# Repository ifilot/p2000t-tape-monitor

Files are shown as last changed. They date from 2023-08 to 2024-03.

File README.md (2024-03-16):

# P2000T Tape Monitor





## Features

This project is still under development. Below a list of features can be found.
Checked features are implemented, unchecked features are work in progress.

- [x] Launch tape files from data cartridge in SLOT2
- [x] Write tape data to data cartridge in SLOT2
- [ ] Write data back to tapes from the data cartridge

## Explainer

In the image below, the working of the data cartridge is schematically shown.
In the conventional approach, the user would start the P2000T and load programs
from the cassette. Under the hood, data is copied from the cassette to the
internal memory after which the program can be started.

The data cartridge essentially imitates this process. Upon boot, a driver is 
loaded from the data cartridge into memory and launched. This driver
scans the external ROM chip for programs and shows a list of those programs. The
user can then select a program and executes it. Upon selection, the program is
first copied from the external chip to the internal RAM chip in the data cartridge.
Next, the driver is unloaded from memory, and the new data is copied from the 
RAM chip to the same position as where normally cassette data is copied. 
Finally, the `RUN` command is executed which starts the program.

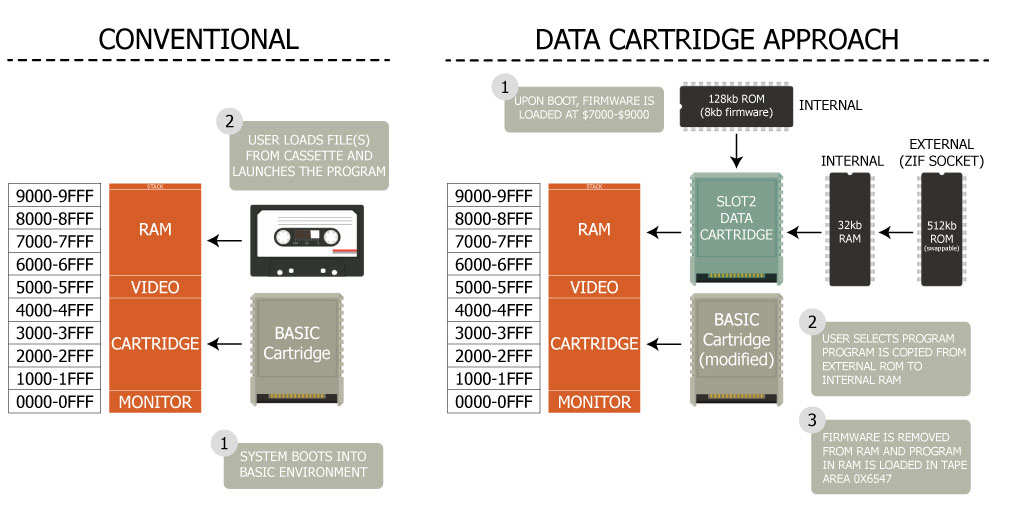
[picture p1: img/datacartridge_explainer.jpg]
Explain how the data cartridge works


## Contents
This repository is organized as follows

* `basicmod`: Modified BASIC ROM. This ROM is needed for the cartridge in SLOT1.
* `cassette-utility`: Source code of the SLOT1 program to copy programs and data
  from the data cassette to the data cartridge.
* `docs`: Technical documentation; mainly needed for development.
* `flasher`: SLOT1 program to transfer the launcher from external ROM chip
  on the data cartridge to the internal ROM.
* `gui`: GUI to add and delete programs from the data cartridge and to format a
  chip.
* `launcher`: Source code of the launcher application.
* `pcb`: PCBs for the SLOT2 data cartridge. Also includes .stl files for the cartridge enclosure.

## Files

The latest version of the files below can be obtained from the action artifacts
of the [last build](https://github.com/ifilot/p2000t-tape-monitor/actions/workflows/build.yml).

* [`BASICBOOTSTRAP.BIN`](https://github.com/ifilot/p2000t-tape-monitor/releases/latest/download/BASICBOOTSTRAP.BIN): 
  Modified BASIC cartridge. This is a SLOT1 cartridge.
* [`CASSETTE_UTILITY.BIN`](https://github.com/ifilot/p2000t-tape-monitor/releases/latest/download/CASSETTE_UTILITY.BIN): 
  Utility for copying files directly from the cassette to the (external) ROM chip. This is a SLOT1 cartridge.
* [`FLASHER.BIN`](https://github.com/ifilot/p2000t-tape-monitor/releases/latest/download/FLASHER.BIN):
  Flasher for the data cartridge driver. This is a SLOT1 cartridge that copies 
  the driver from the external to the internal ROM on the SLOT2 cartridge.
* [`LAUNCHER.BIN`](https://github.com/ifilot/p2000t-tape-monitor/releases/latest/download/LAUNCHER.BIN): 
  Driver for the data cartridge. This driver is stored on the internal ROM of 
  the SLOT2 cartridge.
* [`p2000t-fat-flasher-installer-win64.exe`](https://github.com/ifilot/p2000t-tape-monitor/releases/latest/download/p2000t-fat-flasher-installer-win64.exe): 
  Windows installer for the Flasher GUI. This GUI is used to put cassette files 
  on a ROM chip which can be loaded on the P2000T.

## File system

Data is stored on the ROM using a custom file system. Specifications of the file
system are documented [in a separate file](docs/fat.md).

## FAQ

* Where can I find programs?

  *A rather huge archive of P2000T cassette programs 
  (which is also being actively maintained), can be found in the
  [P2000T Preservation Project](https://github.com/p2000t/software) repository.*
* Where can I find the documentation?

  *All documentation can be found on the [philips-p2000t.nl](https://philips-p2000t.nl) website.*

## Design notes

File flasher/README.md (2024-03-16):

# Flasher

## Purpose

This SLOT1 program allows the user to copy the firmware from bank 1 on an
*external* ROM chip to the *internal* ROM chip.

## Usage

Put the firmware (`launcher-os`) on the external ROM chip and start the P2000T
with this program in SLOT1. Press any key to start the copying procedure. When
done, the copying process is validated on the basis of a checksum. You need
to verify that this checksum matches the expected checksum. The expected 
checksum is provided upon compilation of `launcher-os`.

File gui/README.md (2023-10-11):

# P2000T FAT GUI

## Purpose

User-friendly way of interfacing with P2000T-FAT ROMS using the
PICO-flasher utility.

## Compilation under Linux

Ensure that all dependencies are installed

```bash
sudo apt update && sudo apt install -y qtbase5-dev qt5-qmake libqt5serialport5-dev cmake
```

Create a new build folder and compile the GUI

```
mkdir build && cd build && qmake ../gui && make -j
```

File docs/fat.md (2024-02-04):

# File Allocation Table on ROM chips

This page explains how data is stored on the ROM chips. The Tape monitor uses
the SST39SF0x0 type of ROM chips which contain 128kb, 256kb or 512kb of data
for the 040, 020 and 010 models, respectively.

## Summary

* Each ROM has 2, 4, or 8 banks for a total of 128kb, 256kb, or 512kb of data.
* A bank corresponds to 64kb hosting 60 blocks of 1kb of data each.
* A file is a (not necessarily continuous) set of blocks, corresponding to
  an entry on a tape.
* Each bank has a metadata section of 4kb that holds the metadata of the block
  and of the files.

A schematic overview is given in the figure below.

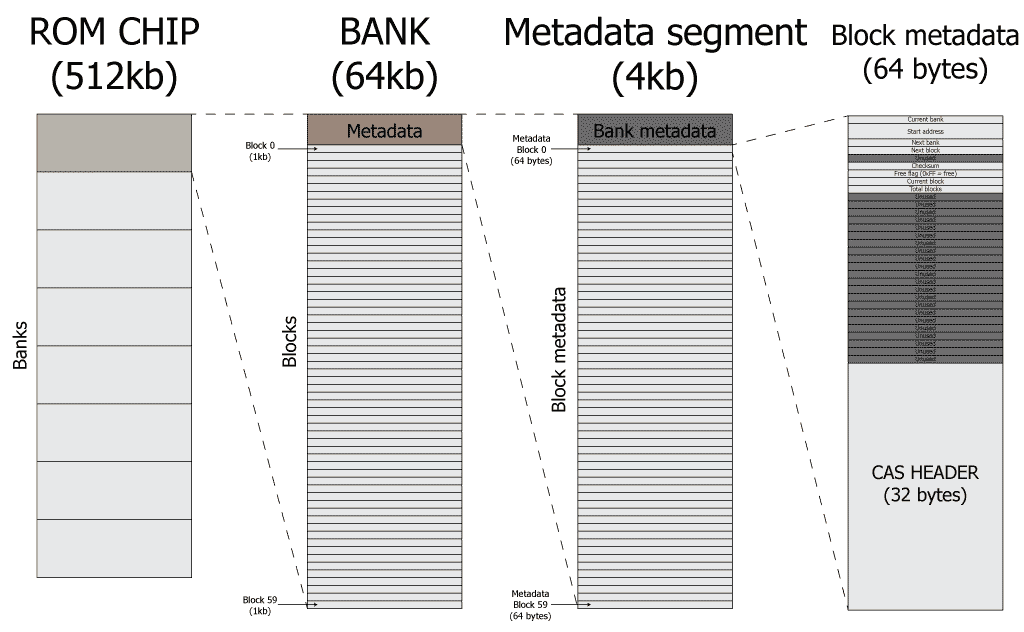
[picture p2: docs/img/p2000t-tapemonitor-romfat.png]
Overview storage model


## Storage model

The first 4kb of each bank are used to store the metadata of that bank. Herein,
the first 256 bytes of the metadata section contain the start blocks for the
files. The next 60 entries correspond to 64 bytes of metadata information for
each block. An schematic overview is provided in the table below.

| Address | Description |
|---|---|
| $0000-$00FF | Bank metadata |
| $0100-$013F | Metadata block 0  |
| $0140-$017F | Metadata block 1  |
| $0180-$01BF | Metadata block 2  |
| $01C0-$01FF | Metadata block 3  |
| $0200-$023F | Metadata block 4  |
| .....-..... | Metadata block i  |
| $0FC0-$0FFF | Metadata block 59 |

Note that because a bank can only contain at most 60 blocks of data, the bank
metadata section will at most use 60 of the in total 256 entries.

### Block metadata

The block metadata segments, each 64kb in size, are divided into a lower and
upper segment. The upper segment is a copy of the cassette metadata as stored
at $6030 in memory when reading from a tape. The upper segment holds a
per block checksum and a reference to the next bank and block if the file
uses more than one block. If not, the default value corresponds to `0xFF`.

| Address | Description | Notes |
|---|---|---|
| $0000 | Current bank  (F)  | |
| $0001-$0002 | Start address (F)  | |
| $0003 | Next bank | $FF when last block |
| $0004 | Next block | $FF when last block |
| $0005 | *Unused* | |
| $0006-$0007 | Checksum | CRC-16, see below |
| $0008 | Free? | $FF if free, else $00 |
| $0009 | Current block | |
| $000A | Total blocks | |
| $000B-$001F | *Unused* | |
| $0020-$003F | CAS header | |

### Storage location of cassette metadata

The CAS header basically corresponds to memory locations $6030-$604F of the
P2000T after reading a block from the cassette. These addresses are hardcoded 
in the P2000T ROM (e.g. 0x0000 - 0x1000) and cannot be changed.

**Note that all values are stored in big endian order**

| Address | RAM Address | Description |
|---|---|---|
| $0020-$0021 | $6030-$6031 | Transfer address |
| $0022-$0023 | $6032-$6033 | File length |
| $0024-$0025 | $6034-$6035 | Record length |
| $0026-$002D | $6036-$603D | Descriptor (1/2) |
| $002E-$0030 | $603E-$6040 | Extension |
| $0031-$0032 | $6041-$6042 | Type |
| $0033-$0034 | $6043-$6044 | Start boot |
| $0035-$0036 | $6045-$6046 | Load |
| $0037-$003E | $6047-$604E | Descriptor (2/2) |
| $003F | $604F | Blocks remaining |

### Checksum

For each 1kb block of data, a 16-bit checksum is generated using the 
CRC-16/XMODEM checksum algorithm. Efficient Z80 source code for the algorithm 
is taken from [here](https://mdfs.net/Info/Comp/Comms/CRC16.htm).
A handy site for generating checksums can be found [here](https://crccalc.com/).

## Formatting

When a ROM is formatted, first all banks are wiped (i.e. set to `0xFF`). Next,
the metadata for each bank is set. This corresponds to 3 bytes per block metadata
section. All other bytes remain at (`0xFF`).

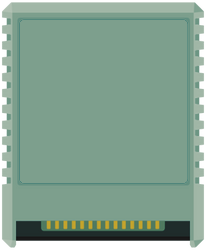
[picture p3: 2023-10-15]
img/cartridge_teal.png

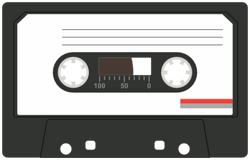
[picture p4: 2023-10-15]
img/cassette.png

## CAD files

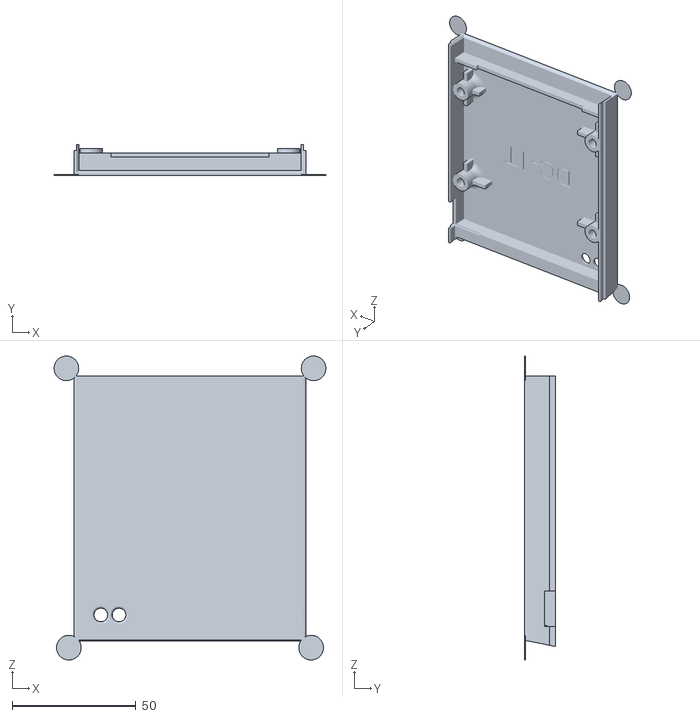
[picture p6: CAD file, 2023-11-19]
pcb/case/p2000t-datacartridge-top.stl
110.0 x 12.5 x 123.0

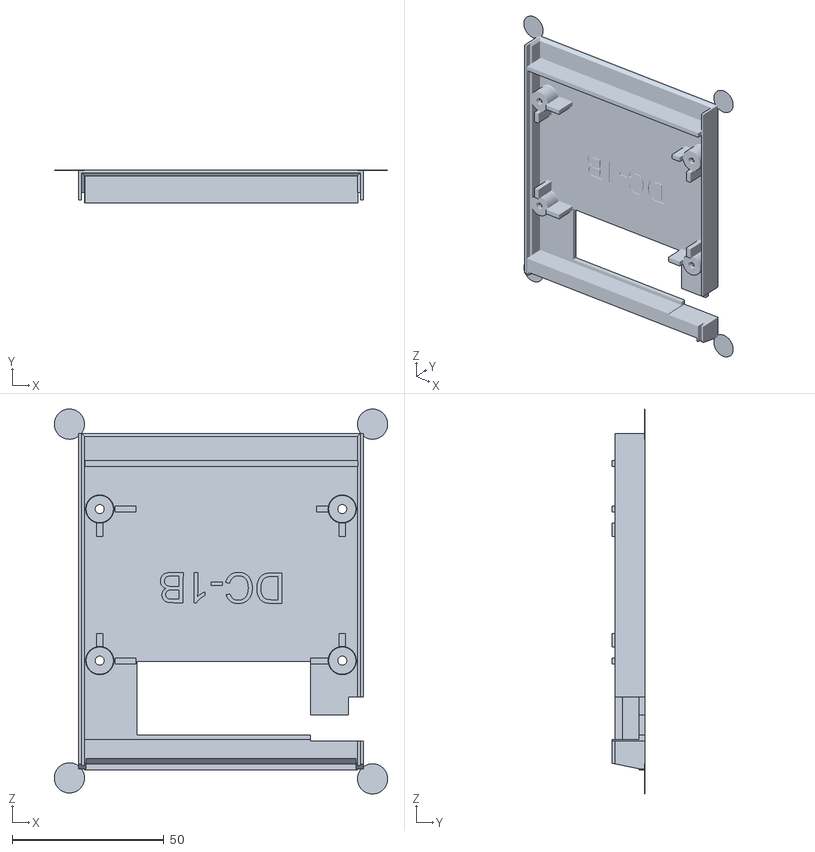
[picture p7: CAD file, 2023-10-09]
pcb/case/p2000t-datacartridge-bottom.stl
110.0 x 11.0 x 127.0

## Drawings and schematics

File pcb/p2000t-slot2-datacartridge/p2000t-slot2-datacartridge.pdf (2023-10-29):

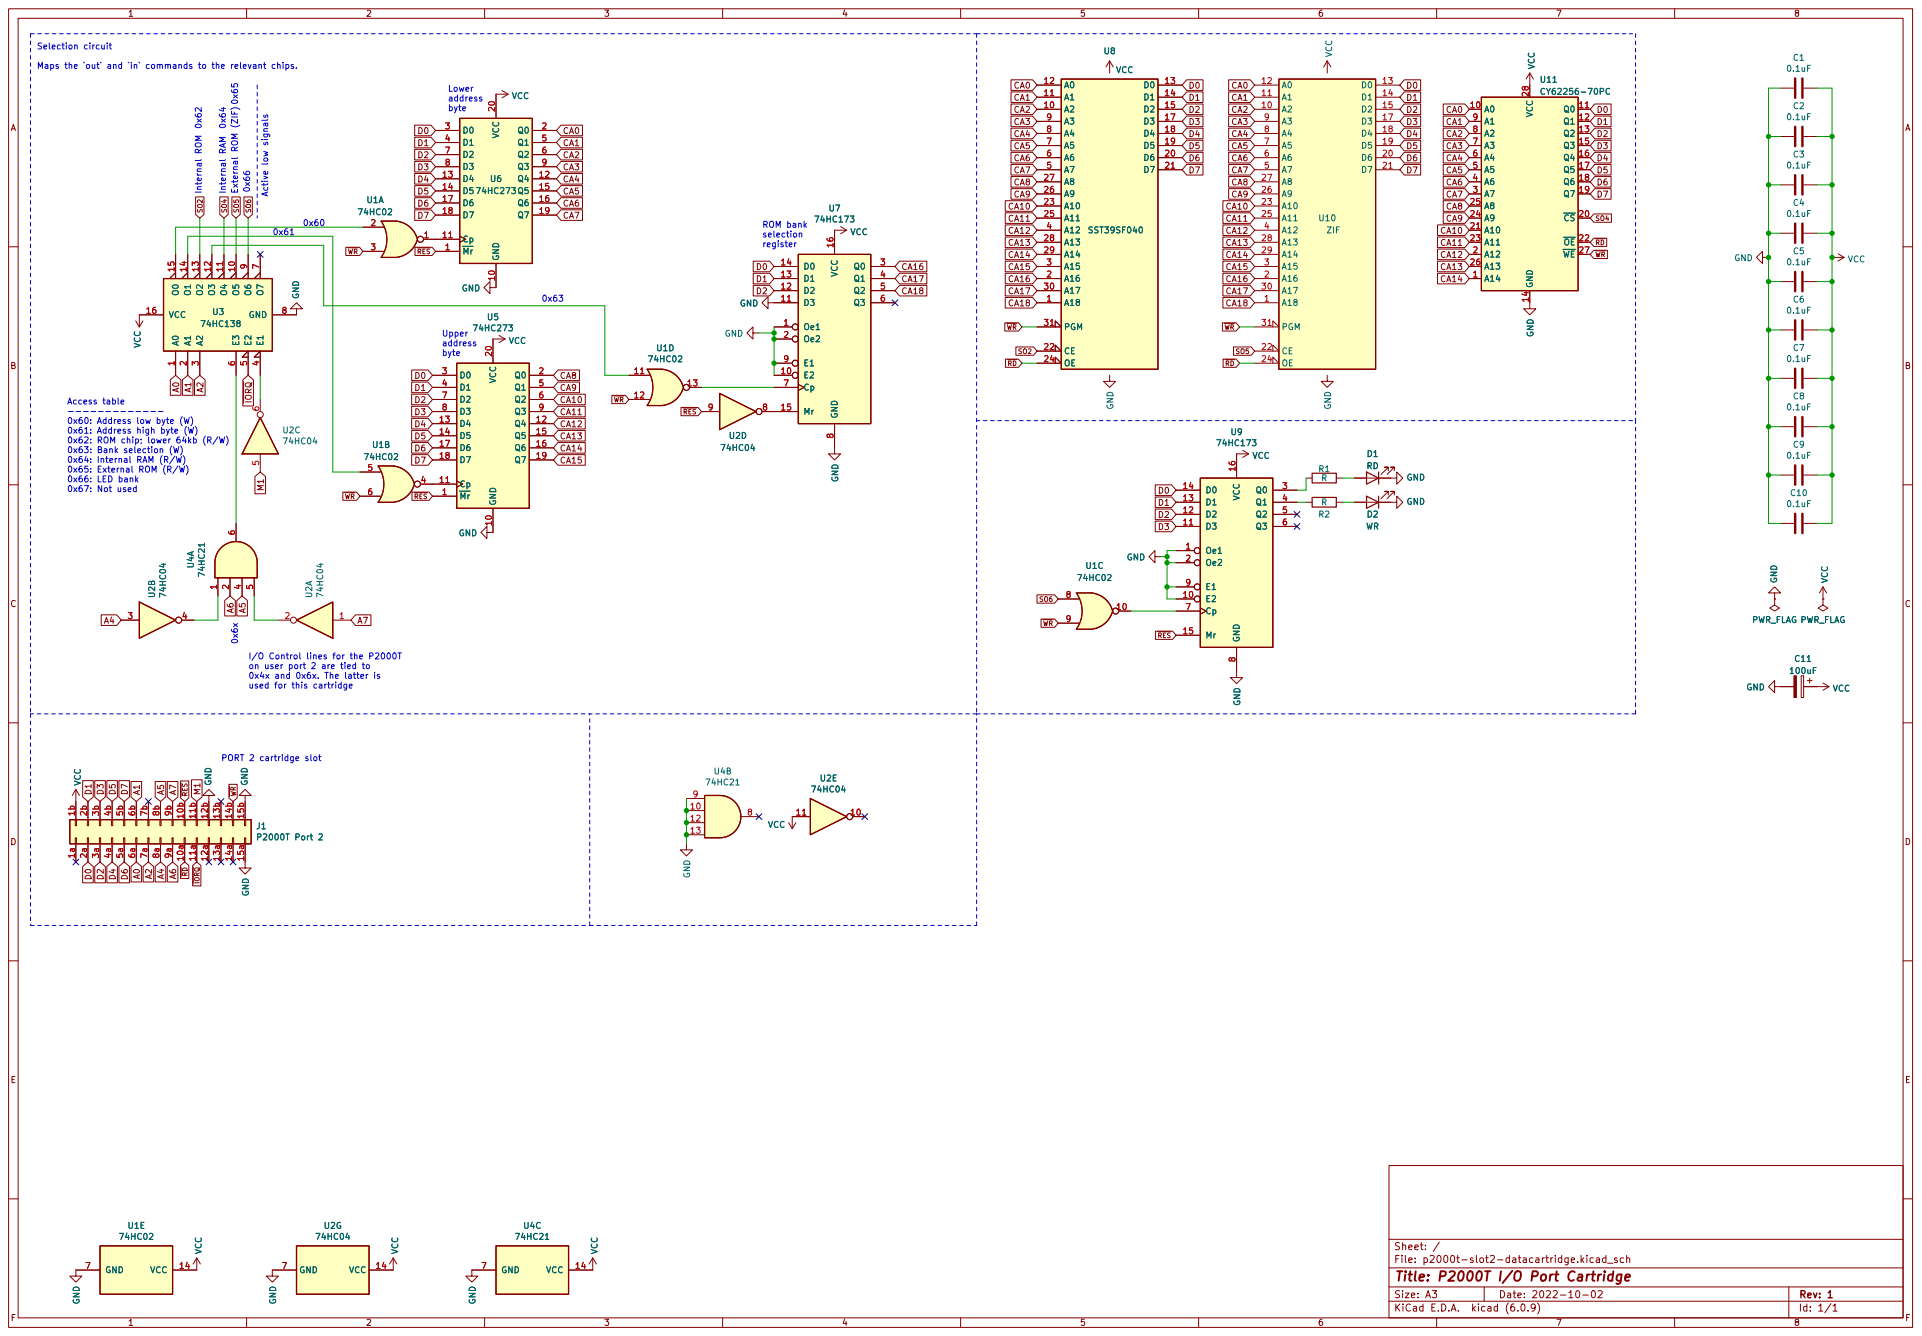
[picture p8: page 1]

PORT 2 cartridge slot 0x64 Selection circuit Maps the `out` and `in` commands to the relevant chips. 0x65

0x4x and 0x6x. The latter is used for this cartridge Access table
------------- 0x60: Address low byte (W)

I/O Control lines for the P2000T
on user port 2 are tied to

File: p2000t-slot2-datacartridge.kicad_sch Sheet: /
Id: 1/1 Title: P2000T I/O Port Cartridge

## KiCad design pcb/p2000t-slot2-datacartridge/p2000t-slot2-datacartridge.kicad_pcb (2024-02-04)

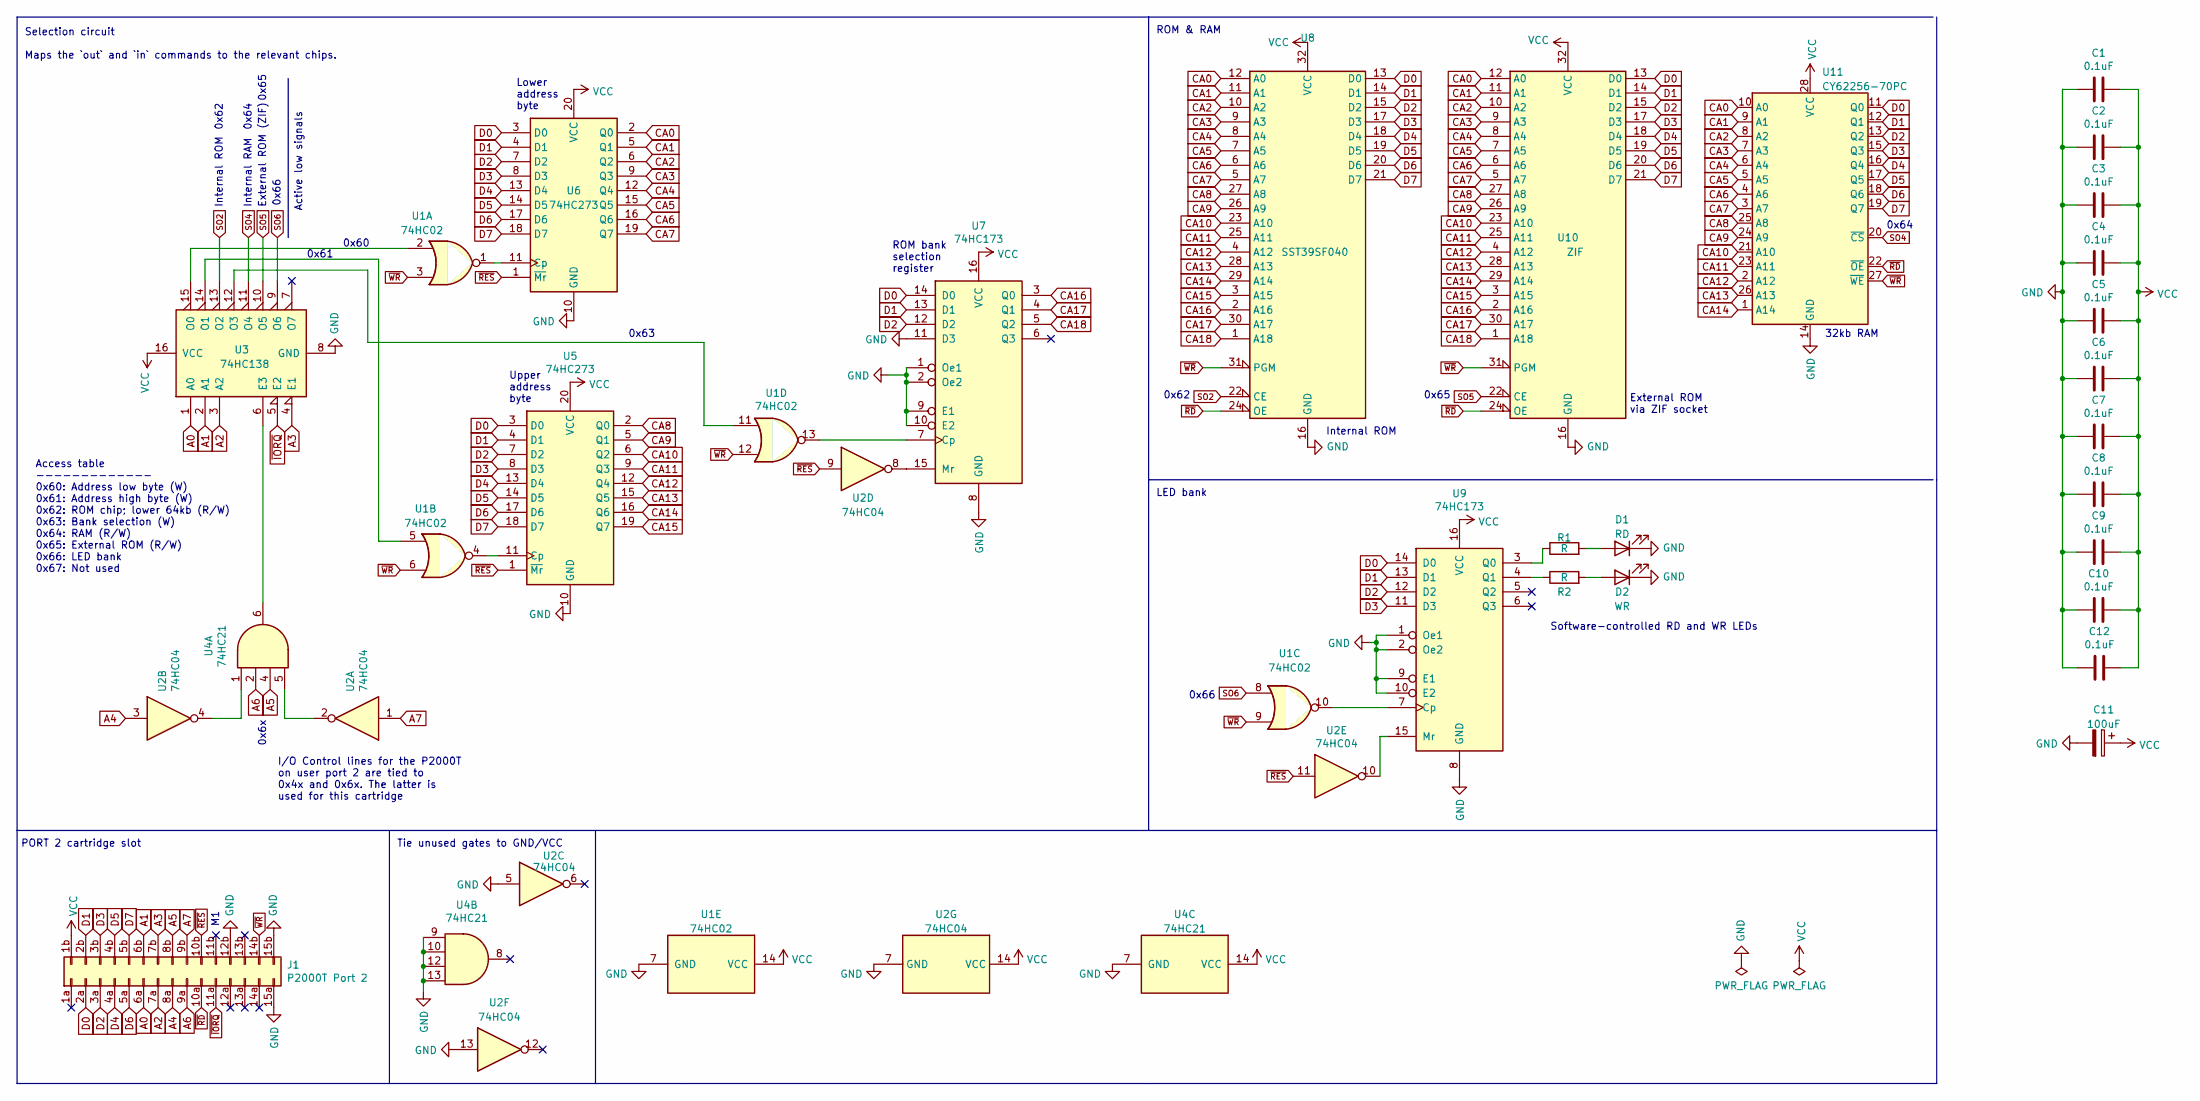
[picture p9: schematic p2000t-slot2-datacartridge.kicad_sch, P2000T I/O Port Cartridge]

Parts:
C1, C2, C3, C4, C5, C6, C7, C8, C9, C10, C12: 0.1uF; C_Disc_D5.0mm_W2.5mm_P5.00mm
C11: 100uF; CP_Radial_D6.3mm_P2.50mm
D1: RD; LED_D5.0mm
D2: WR; LED_D5.0mm
J1: P2000T Port 2; p2000t_cartridge_edge
R1, R2: R; R_Axial_DIN0207_L6.3mm_D2.5mm_P7.62mm_Horizontal
U1: 74HC02; DIP-14_W7.62mm_Socket
U2: 74HC04; DIP-14_W7.62mm_Socket
U3: 74HC138; DIP-16_W7.62mm_Socket
U4: 74HC21; DIP-14_W7.62mm_Socket
U5, U6: 74HC273; DIP-20_W7.62mm_Socket
U7, U9: 74HC173; DIP-16_W7.62mm_Socket
U8: SST39SF040; PLCC-32_THT-Socket
U10: ZIF; DIP_Socket-32_W11.9_W12.7_W15.24_W17.78_W18.5_3M_232-1285-0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
U11: CY62256-70PC; DIP-28_W15.24mm_Socket

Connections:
A0: J1.6a, U3.1 (A0)
A1: J1.6b, U3.2 (A1)
A2: J1.7a, U3.3 (A2)
A3: J1.7b, U3.4 (E1)
A4: J1.8a, U2.3
A5: J1.8b, U4.4
A6: J1.9a, U4.2
A7: J1.9b, U2.1
CA0: U6.2 (Q0), U8.12 (A0), U10.12 (A0), U11.10 (A0)
CA1: U6.5 (Q1), U8.11 (A1), U10.11 (A1), U11.9 (A1)
CA2: U6.6 (Q2), U8.10 (A2), U10.10 (A2), U11.8 (A2)
CA3: U6.9 (Q3), U8.9 (A3), U10.9 (A3), U11.7 (A3)
CA4: U6.12 (Q4), U8.8 (A4), U10.8 (A4), U11.6 (A4)
CA5: U6.15 (Q5), U8.7 (A5), U10.7 (A5), U11.5 (A5)
CA6: U6.16 (Q6), U8.6 (A6), U10.6 (A6), U11.4 (A6)
CA7: U6.19 (Q7), U8.5 (A7), U10.5 (A7), U11.3 (A7)
CA8: U5.2 (Q0), U8.27 (A8), U10.27 (A8), U11.25 (A8)
CA9: U5.5 (Q1), U8.26 (A9), U10.26 (A9), U11.24 (A9)
CA10: U5.6 (Q2), U8.23 (A10), U10.23 (A10), U11.21 (A10)
CA11: U5.9 (Q3), U8.25 (A11), U10.25 (A11), U11.23 (A11)
CA12: U5.12 (Q4), U8.4 (A12), U10.4 (A12), U11.2 (A12)
CA13: U5.15 (Q5), U8.28 (A13), U10.28 (A13), U11.26 (A13)
CA14: U5.16 (Q6), U8.29 (A14), U10.29 (A14), U11.1 (A14)
CA15: U5.19 (Q7), U8.3 (A15), U10.3 (A15)
CA16: U7.3 (Q0), U8.2 (A16), U10.2 (A16)
CA17: U7.4 (Q1), U8.30 (A17), U10.30 (A17)
CA18: U7.5 (Q2), U8.1 (A18), U10.1 (A18)
D0: J1.2a, U5.3 (D0), U6.3 (D0), U7.14 (D0), U8.13 (D0), U9.14 (D0), U10.13 (D0), U11.11 (Q0)
D1: J1.2b, U5.4 (D1), U6.4 (D1), U7.13 (D1), U8.14 (D1), U9.13 (D1), U10.14 (D1), U11.12 (Q1)
D2: J1.3a, U5.7 (D2), U6.7 (D2), U7.12 (D2), U8.15 (D2), U9.12 (D2), U10.15 (D2), U11.13 (Q2)
D3: J1.3b, U5.8 (D3), U6.8 (D3), U8.17 (D3), U9.11 (D3), U10.17 (D3), U11.15 (Q3)
D4: J1.4a, U5.13 (D4), U6.13 (D4), U8.18 (D4), U10.18 (D4), U11.16 (Q4)
D5: J1.4b, U5.14 (D5), U6.14 (D5), U8.19 (D5), U10.19 (D5), U11.17 (Q5)
D6: J1.5a, U5.17 (D6), U6.17 (D6), U8.20 (D6), U10.20 (D6), U11.18 (Q6)
D7: J1.5b, U5.18 (D7), U6.18 (D7), U8.21 (D7), U10.21 (D7), U11.19 (Q7)
GND: C1.2, C2.2, C3.2, C4.2, C5.2, C6.2, C7.2, C8.2, C9.2, C10.2, C11.2, C12.2, D1.1 (K), D2.1 (K), J1.12b, J1.15a, J1.15b, U1.7 (GND), U2.5, U2.7 (GND), U2.13, U3.8 (GND), U4.7 (GND), U4.9, U4.10, U4.12, U4.13, U5.10 (GND), U6.10 (GND), U7.1 (Oe1), U7.2 (Oe2), U7.8 (GND), U7.9 (E1), U7.10 (E2), U7.11 (D3), U8.16 (GND), U9.1 (Oe1), U9.2 (Oe2), U9.8 (GND), U9.9 (E1), U9.10 (E2), U10.16 (GND), U11.14 (GND)
unnamed: D1.2 (A), R1.2
unnamed: D2.2 (A), R2.2
unnamed: U2.2, U4.5
unnamed: U2.4, U4.1
unnamed: U3.6 (E3), U4.6
unnamed: U1.2, U3.15 (O0)
unnamed: U1.5, U3.14 (O1)
unnamed: U1.11, U3.12 (O3)
unnamed: U1.4, U5.11 (Cp)
unnamed: U1.1, U6.11 (Cp)
unnamed: U1.13, U7.7 (Cp)
unnamed: U2.8, U7.15 (Mr)
unnamed: U1.10, U9.7 (Cp)
unnamed: U2.10, U9.15 (Mr)
unnamed: R1.1, U9.3 (Q0)
unnamed: R2.1, U9.4 (Q1)
SO2: U3.13 (O2), U8.22 (CE)
SO4: U3.11 (O4), U11.20 (~CS)
SO5: U3.10 (O5), U10.22 (CE)
SO6: U1.8, U3.9 (O6)
VCC: C1.1, C2.1, C3.1, C4.1, C5.1, C6.1, C7.1, C8.1, C9.1, C10.1, C11.1, C12.1, J1.1b, U1.14 (VCC), U2.14 (VCC), U3.16 (VCC), U4.14 (VCC), U5.20 (VCC), U6.20 (VCC), U7.16 (VCC), U8.32 (VCC), U9.16 (VCC), U10.32 (VCC), U11.28 (VCC)
~IORQ: J1.11a, U3.5 (E2)
~RD: J1.10a, U8.24 (OE), U10.24 (OE), U11.22 (~OE)
~RES: J1.10b, U2.9, U2.11, U5.1 (~Mr), U6.1 (~Mr)
~WR: J1.14b, U1.3, U1.6, U1.9, U1.12, U8.31 (PGM), U10.31 (PGM), U11.27 (~WE)

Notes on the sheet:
Active low signals
32kb RAM
0x64
Access table ------------- 0x60: Address low byte (W) 0x61: Address high byte (W) 0x62: ROM chip; lower 64kb (R/W) 0x63: Bank selection (W) 0x64: RAM (R/W) 0x65: External ROM (R/W) 0x66: LED bank 0x67: Not used
Tie unused gates to GND/VCC
Internal ROM
PORT 2 cartridge slot
External ROM via ZIF socket
0x6x
Software-controlled RD and WR LEDs
ROM bank selection register
0x66
I/O Control lines for the P2000T on user port 2 are tied to 0x4x and 0x6x. The latter is used for this cartridge
0x60
ROM & RAM
Selection circuit Maps the `out` and `in` commands to the relevant chips.
0x65
Upper address byte
0x63
External ROM (ZIF)
0x62
0x61
Lower address byte
LED bank
Internal RAM

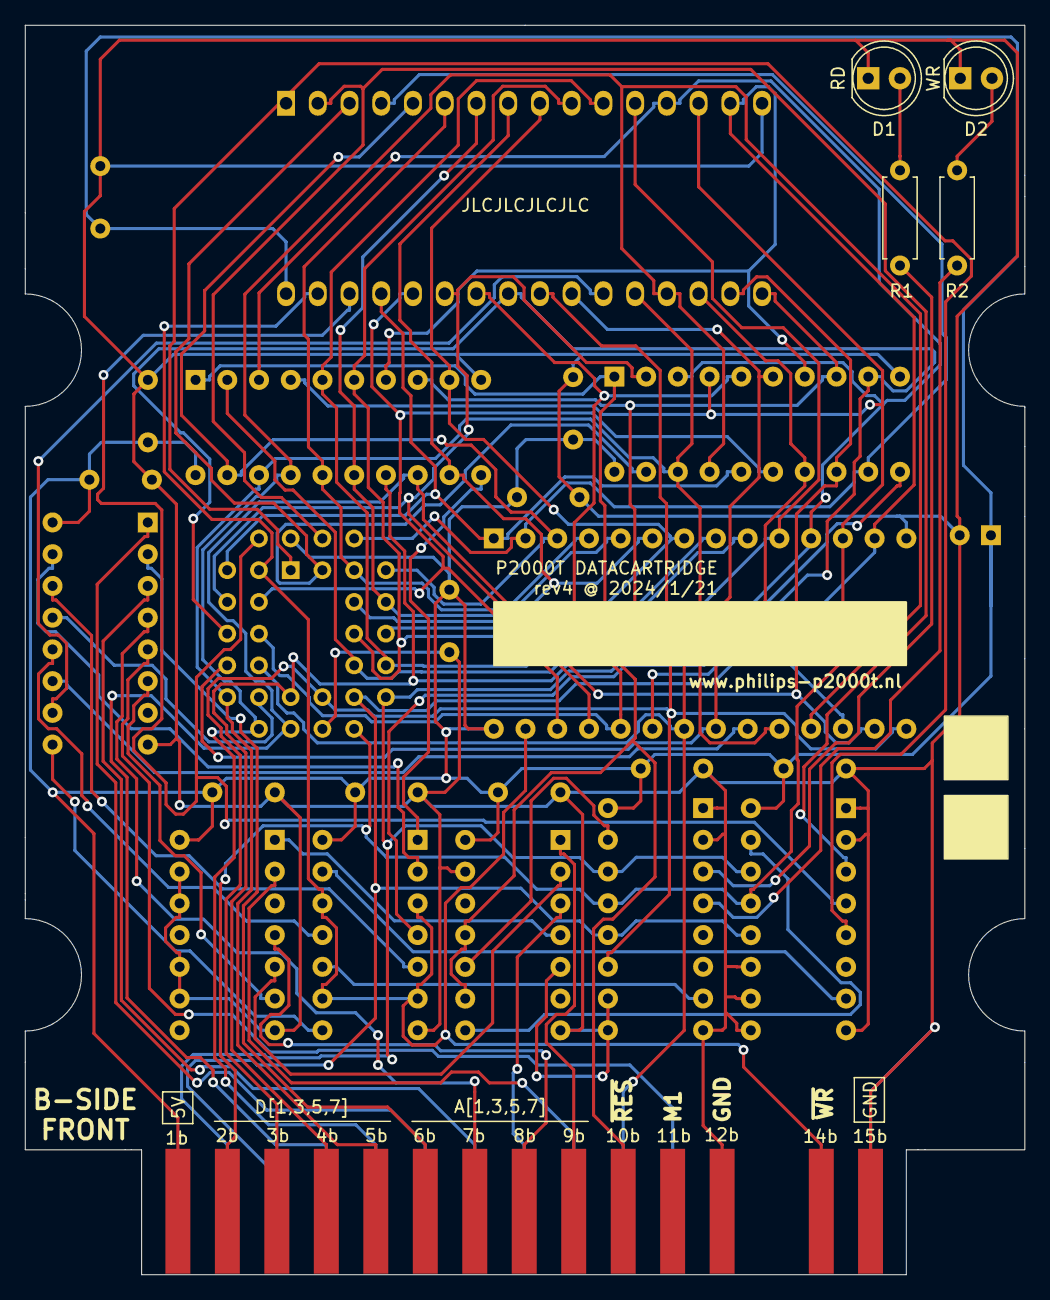
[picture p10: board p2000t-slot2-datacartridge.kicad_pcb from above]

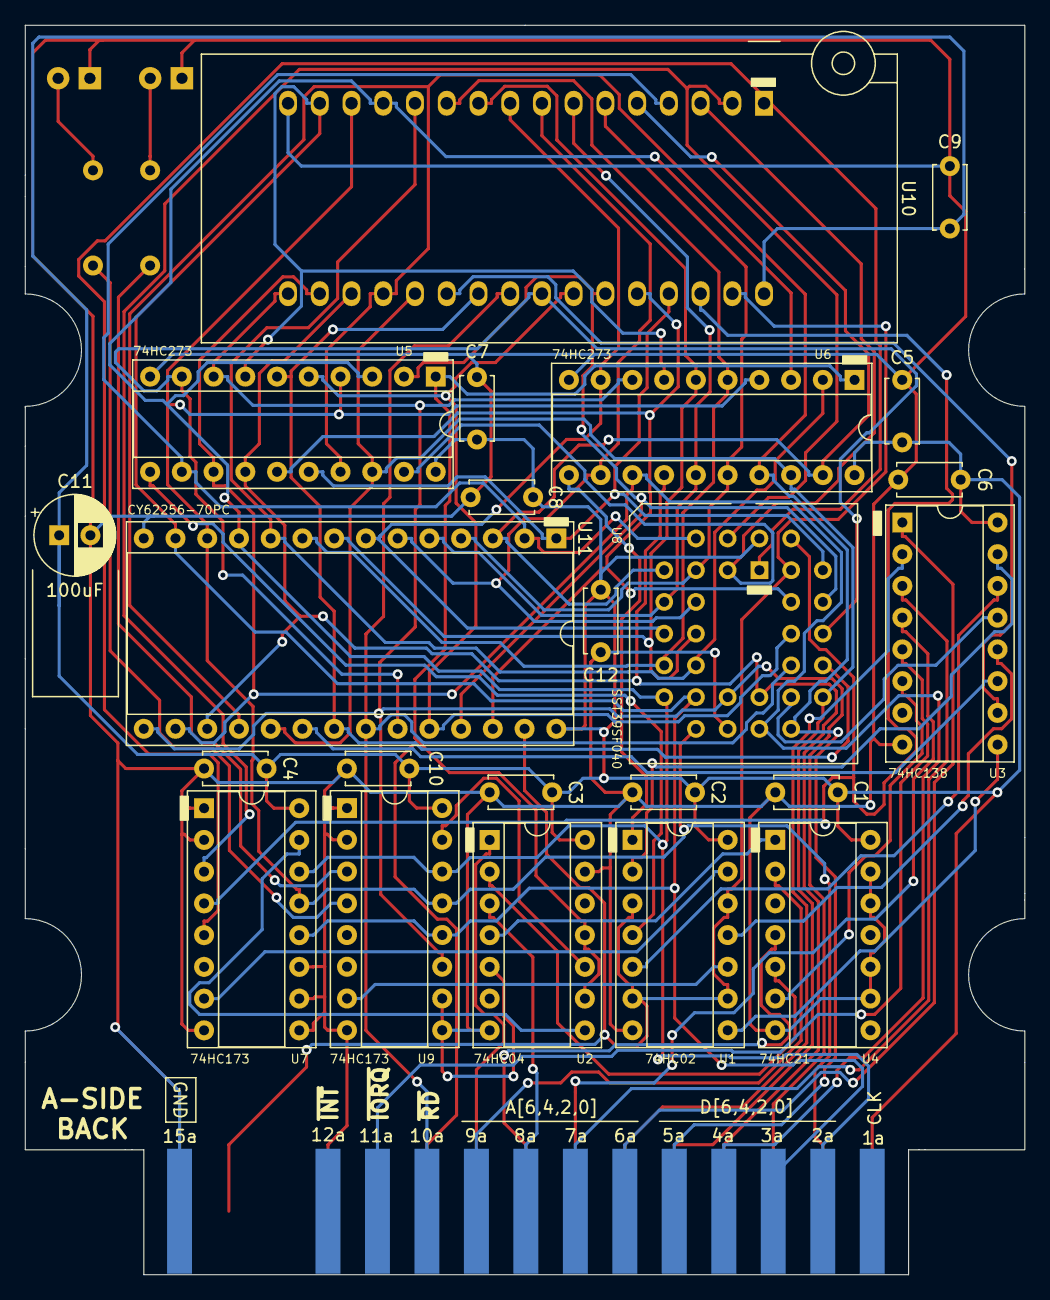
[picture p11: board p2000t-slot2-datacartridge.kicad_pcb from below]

Board: 2 copper layers, 80.0 x 100.0 mm, 28 parts (24 on the bottom side), 61 nets.

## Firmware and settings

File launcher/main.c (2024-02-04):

#include <string.h>
#include <stdint.h>
#include <stdio.h>
#include <stdlib.h>

#include "sst39sf.h"
#include "programs.h"
#include "ram.h"
#include "memory.h"
#include "config.h"
#include "leds.h"
#include "stack.h"

// set printf io
#pragma printf "%u %X %s"

// forward declarations
void init(void);
void handle_key(uint8_t key);
uint8_t handle_keybuffer_return(void);

// store program selection keys
char keybuffer[4] = {0x00, 0x00, 0x00, 0x00};
uint8_t numkeysbuf = 0;
uint8_t flag_validation = 1; // whether to perform validation on the loaded program

void main(void) {
    init();

    // set rom bank to zero
    sst39sf_set_bank(0);

    // set rom pointer to zero
    uint16_t romptr = 0x0000;

    // read the programs on the cartridge and place the
    // contents on the cartridge RAM
    __nrprogs = get_number_programs();
    uint16_t offset = 0;
    read_programs_offset(offset);
    print_programs(16, offset);
    uint8_t exit_loop = 1;

    while(exit_loop != 0) {
        if(keymem[0x0C] > 0) {
            for(uint8_t i=0; i<keymem[0x0C]; i++) {
                switch(keymem[i]) {
                    case 25:  // 'n'
                        if(__nrprogs <= 16) { // if program size is smaller than 16, do nothing
                            break;
                        }
                        if(offset + 16 < (__nrprogs - 16)) {
                            offset += 16;
                        } else {
                            offset = __nrprogs - 16;
                        }
                        read_programs_offset(offset);
                        print_programs(16, offset);
                        break;
                    case 53: // 'p'
                        if(__nrprogs <= 16) { // if program size is smaller than 16, do nothing
                            break;
                        }
                        if(offset > 16) {
                            offset -= 16;
                        } else {
                            offset = 0;
                        }
                        read_programs_offset(offset);
                        print_programs(16, offset);
                        break;
                    case 31: // 'v'
                        flag_validation ^= 1; // toggle first bit
                        sprintf(&vidmem[0x50*20+1], "Checksum validation %s. [V]", flag_validation == 1 ? "enabled" : "disabled");
                        break;
                    case 46:
                    case 63:
                    case 4:
                    case 7:
                    case 5:
                    case 1:
                    case 6:
                    case 54:
                    case 41:
                    case 45:
                    case 44:
                        handle_key(keymem[i]);
                        break;
                    case 52: // enter
                        exit_loop = handle_keybuffer_return();
                        if(exit_loop != 0) {
                            read_programs_offset(offset);
                            print_programs(16, offset);
                        }
                        break;
                    default:
                        break;
                }
            }
            keymem[0x0C] = 0;
        }
    }
}

void handle_key(uint8_t key) {
    if(key == 44) { // backspace
        if(numkeysbuf > 0) {
            numkeysbuf--;
        }
        keybuffer[numkeysbuf] = ' ';
    } else {
        if(numkeysbuf < 3) {
            switch(key) {
                case 46:
                   keybuffer[numkeysbuf] = '1';
                   break;
                case 63:
                   keybuffer[numkeysbuf] = '2';
                   break;
                case 4:
                   keybuffer[numkeysbuf] = '3';
                   break;
                case 7:
                   keybuffer[numkeysbuf] = '4';
                   break;
                case 5:
                   keybuffer[numkeysbuf] = '5';
                   break;
                case 1:
                   keybuffer[numkeysbuf] = '6';
                   break;
                case 6:
                   keybuffer[numkeysbuf] = '7';
                   break;
                case 54:
                   keybuffer[numkeysbuf] = '8';
                   break;
                case 41:
                   keybuffer[numkeysbuf] = '9';
                   break;
                case 45:
                   keybuffer[numkeysbuf] = '0';
                   break;
            }
            numkeysbuf++;
        } else {
            return;
        }
    }
    vidmem[0x50*22+34] = COL_WHITE;
    memcpy(&vidmem[0x50*22+35], keybuffer, 3);
}

uint8_t handle_keybuffer_return(void) {
    uint16_t progid = strtoul(keybuffer, 0x00, 10);

    if(progid > 0 && progid <= __nrprogs) {

        clearscreen();
        vidmem[0x50*1] = 0x06;
        vidmem[0x50*1+1] = 0x0D;

        char progname[17];
        memset(progname, 0x00, 17);
        get_progname(progid-1, progname);
        sprintf(&vidmem[0x50*1+2], "Loading program: %s", progname);

        // write deploy location in memory
        uint16_t deploy = get_deploy_location(progid-1);
        write_ram(0x8000-4, (uint8_t)(deploy & 0xFF));
        write_ram(0x8000-3, (uint8_t)(deploy >> 8));
        sprintf(&vidmem[0x50*3], "Deploying program to: 0x%04X", deploy);

        uint16_t prgsize = build_linked_list(progid-1);
        //print_linked_list(22);
        copyprogramlinkedlist();

        // perform validation on the RAM chip
        if(flag_validation == 1) {
            validatelinkedlist();

            sprintf(&vidmem[0x50 * 23], "Press any key to start the program.");
            keymem[0x0C] = 0;
            while(keymem[0x0C] == 0) {} // wait until a key is pressed
        }

        // write number of bytes in memory, note that prgsize is stored
        // in big endian order
        write_ram(0x8000-2, (uint8_t)(prgsize & 0xFF));
        write_ram(0x8000-1, (uint8_t)(prgsize >> 8));

        return 0;

    } else {
        sprintf(&vidmem[0x50*10], "Invalid program id: %03u", progid);
    }

    // clean video buffer
    memset(keybuffer, 0x00, 3);
    memcpy(&vidmem[0x50*21+34], keybuffer, 3);
    numkeysbuf = 0;

    return 1;
}

void init(void) {
    clearscreen();
    ledbank_init();

    vidmem[0x0000] = 0x06;    // cyan color
    vidmem[0x0001] = 0x0D;    // double height

    static const char str1[] = "Launcher";
    memcpy(&vidmem[0x0002], str1, strlen(str1));

    // show debug information about BASIC locations and stack pointer
    // uint16_t basictop = memory[0x63b8] | (uint16_t)memory[0x63b9] << 8; // highest address that BASIC is allowed to use
    // uint16_t stringspace_size = memory[0x6258] | (uint16_t)memory[0x6259] << 8; // start of string space
    // sprintf(&vidmem[0x50*19], "Basic pointers: %04X / %04X / %04X", basictop, stringspace_size, get_stack_pointer());

    // show version and compile information
    vidmem[0x50*23] = COL_BLUE;
    sprintf(&vidmem[0x50*23+1], "Version %s (%s, %s)", __VERSION__, __DATE__, __TIME__);

    // determine chip id
    uint16_t chip_id = sst39sf_get_chip_id();

    switch(chip_id & 0xFF) {
        case 0xB5:
            sprintf(&vidmem[21], "%s", "SST39SF010 (128kb)");
            __nrbanks = 2;
            break;
        case 0xB6:
            sprintf(&vidmem[21], "%s", "SST39SF020 (256kb)");
            __nrbanks = 4;
            break;
        case 0xB7:
            sprintf(&vidmem[21], "%s", "SST39SF040 (512kb)");
            __nrbanks = 8;
            break;
        default:
            // stop initialization and throw error message
            sprintf(&vidmem[0x50 * 10], "%s", "[ERROR]: Cannot detect external chip");
            sprintf(&vidmem[0x50 * 11], "%s", "Ensure a ROM is inserted in the data");
            sprintf(&vidmem[0x50 * 12], "%s", "cartridge and press RESET");
            while(0 == 0){}; // put in infinite loop
    }

    vidmem[0x50*20] = COL_MAGENTA;
    sprintf(&vidmem[0x50*20+1], "Checksum validation enabled. [v]");
    vidmem[0x50*21] = COL_BLUE;
    sprintf(&vidmem[0x50*21+1], "Press [n/p] to scroll between pages.");
    vidmem[0x50*22] = COL_BLUE;
    sprintf(&vidmem[0x50*22+1], "Select program by entering [0-9]: ");
}

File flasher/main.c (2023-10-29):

#include <string.h>
#include <stdint.h>
#include <stdio.h>
#include <stdlib.h>

#include "sst39sf.h"
#include "memory.h"
#include "util.h"
#include "copy.h"
#include "leds.h"
#include "config.h"

// forward declarations
void init(void);

int main(void) {
    init();

    uint8_t row = 0;
    vidmem[0x0000] = 0x06;    // cyan color
    vidmem[0x0001] = 0x0D;    // double height
    const char titlestr[] = "Datacartridge flasher";
    memcpy(&vidmem[0x0002], titlestr, strlen(titlestr));
    row += 3;

    const char msgstart[] = "Press any key to start flashing.";
    memcpy(&vidmem[row * 0x50], msgstart, strlen(msgstart));

    while(keymem[0x0C] == 0) {}

    clearline(row);
    const char copyfirmwarestr[] = "Copying firmware (8kb). Please wait...";
    memcpy(&vidmem[row * 0x50], copyfirmwarestr, strlen(copyfirmwarestr));

    sst39sf_set_bank(0);
    sst39sf_set_bank_romint(0);

    // only wipe the first two sectors as the launch-os is (by design)
    // constrainted to 0x2000 bytes
    led_wr_on();
    for(uint16_t i=0; i<2; i++) { // loop over sectors
        sst39sf_wipe_sector_romint(i * 0x1000);
    }
    led_wr_off();

    // copy external bank0 to internal rom chip
    led_wr_on();
    copyfirsttwosectors();
    led_wr_off();

    clearline(row);
    const char msgdone[] = "Completed data transfer: 8kb.";
    memcpy(&vidmem[row*0x50], msgdone, strlen(msgdone));

    row += 2;
    const char calccrc16str[] = "Calculating CRC16 checksums...";
    memcpy(&vidmem[0x50*row], calccrc16str, strlen(calccrc16str));

    // calculate CRC16
    led_rd_on();
    calculatecrc16();
    led_rd_off();

    clearline(row);
    const char crcstr[] = "CRC16 checksums:";
    memcpy(&vidmem[0x50*row], crcstr, strlen(crcstr));
    row++;
    for(uint8_t i=0; i<2; i++) {
        printhex(row*0x50+i*5, highmem9000[i*2]);
        printhex(row*0x50+i*5+2, highmem9000[i*2+1]);
    }

    row += 2;
    const char outputstr[] = "Output first 64 bytes:";
    memcpy(&vidmem[0x50*row], outputstr, strlen(outputstr));
    for(uint8_t i=0; i<8; i++) {
        row++;
        for(uint8_t j=0; j<8; j++) {
            printhex(row*0x50+j*3, sst39sf_read_byte_romint(i*8+j));
        }
    }

    row += 2;
    const char alldonestr1[] = "Flashing complete. Please carefully";
    memcpy(&vidmem[0x50*row], alldonestr1, strlen(alldonestr1));

    row++;
    const char alldonestr2[] = "verify that the checksums are correct.";
    memcpy(&vidmem[0x50*row], alldonestr2, strlen(alldonestr2));

    return 0;
}

void init(void) {
    ledbank_init(); // turn all leds off
    sprintf(&vidmem[0x50*22], "Version: %s", __VERSION__);
    sprintf(&vidmem[0x50*23], "Compiled at: %s / %s", __DATE__, __TIME__);
}

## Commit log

2023-10-09 Adding firmware, PCB schematics, documentation (#4)
    * Initial commit file info
    * Building linked list
    * Initial commit file deletion
    * Adding headers
    * Attempt to format header
    * Expanding on file deletion procedure
    * Migrating register functions to memory
    * Succesful wipe
    * Removing log messages
    * Initial commit overview ROM
    * Fixing overview screen
    * Showing file blocks and adding modal
    * Adding slot2 PCB
    * Cleaning up repo
    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
    [p2000t-datacartridge-bottom.stl, p2000t-datacartridge-top.stl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]
2023-10-14 Adding features (#7)
    * Adding chip formatting
    * Implementing rom formatting and replacing icon
    * Checking for ROM id, fixing bug in program numbers, expanding to 39sf010 and 39sf020 chips
    * Adding version numbers and polishing launch-os
    * Expanding CI/CD
    [main.c, upload.py]
2023-10-15 Patch version 0.2.1 (#8)
    * Improving exception handling
    * Fixing CMakeList.txt
    * Set filesize of flasher to 16k and launcher-os to 8k
    [main.c, main.cpp]
2023-10-15 Removing duplicate case files
    [p2000t-datacartridge-bottom.stl, p2000t-datacartridge-top.stl]
2023-10-29 Patch 0.3.0 (#9)
    * Improving lay-out board
    * Fixing incorrect layer in gerber files
    * Initial commit rev2 and implementing LEDs in firmware flasher
    * Fixing bug that triggered undefined behavior when writing to FAT chip
    * Fixing incorrect RES line
    * Building rev2 of the data cartridge
    * Refactoring serial interface
    * Adding leds to launcher
    * Adding new emulator
    * Expanding README
    * Adding .dll files
    * Adding missing files
    * Adding LEDs to launcher
    * Fixing bugs, adding icons, adding explainers
    [p2000t-slot2-datacartridge-B_Cu.gbr, p2000t-slot2-datacartridge-B_Mask.gbr, p2000t-slot2-datacartridge-B_Paste.gbr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]
2023-11-19 Tuning case
    [p2000t-datacartridge-top.stl]
2024-01-01 Improved Datacartridge PCB (#10)
    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
    [p2000t-slot2-datacartridge-B_Cu.gbr, p2000t-slot2-datacartridge-B_Mask.gbr, p2000t-slot2-datacartridge-B_Paste.gbr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]
2024-01-03 Patch 0.4.0 (#11)
    * Initial commit cassette-utility
    * Retrieving data from tape
    * Implementing file progression
    * Implementing copying files from cassette to chip
    * Fixing reference in build.yml
    * Polishing UI
    * Making slight adjustment to launcher and bootstrap
    * Fix bug in deployment of BASIC ROM
    * Uploading checksums
    * Fixing ids
    * Installing numpy
    * Another attempt
    * Removing main files
    * Patching compilation instructions
    [p2000t-slot2-datacartridge.kicad_sch]
2024-02-04 Revision 3 and 4 of the PCB (#12)
    * Initial commit revision
    * Interim commit
    * Rerouting
    * Fixing bug in PCB
    [p2000t-slot2-datacartridge-B_Cu.gbr, p2000t-slot2-datacartridge-B_Mask.gbr, p2000t-slot2-datacartridge-B_Paste.gbr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]
2024-02-04 Develop (#13)
    * Adding RAM validation
    * Polishing lay-out and optimizing code
    * Allow loading of programs at different deploy addresses, removing obsolete source code.
    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
    [main.c]

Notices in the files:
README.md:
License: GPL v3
